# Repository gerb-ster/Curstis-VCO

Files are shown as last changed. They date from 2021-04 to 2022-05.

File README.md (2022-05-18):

# Curtis-VCO

This module is based on the classic CEM3340 VCO chip, although I’m using a AS3340 clone. I’ve took some inspiration from the Maximus VCO design from Thomas Henry. The CEM3340 outputs 3 waveforms with different output levels. To achieve a uniform 10 vpp output around 0 volt, I used a series of op-amps. In the first step the 3 levels is attenuated to 10 vpp, in the next step it’s being offset with 5v to make it swing around 0 volt. I’ve used a trimpot to fine-tune the offset.

The triangle output is then used to ‘wave shape’ a sine output. For this, I also used a classic design from Thomas.

I’ve already made some changes to the PCB design, there was an issue with the power rails on the IO board (hence the bodge wire), some transistor values where wrong, and I made some more room for a good timing cap.

### Update 18-05-2022

Small changes have been made to the io-board to fix an issue with PWM range knob. If you have an older board, you can remove R51 from the ioboard and replace it with a wire and replace R49 with a 91k resistor.

## Status: Finished

- done: first schematic & board design
- done: breadboard and test
- done: design frontpanel
- done: order PCB and build prototype

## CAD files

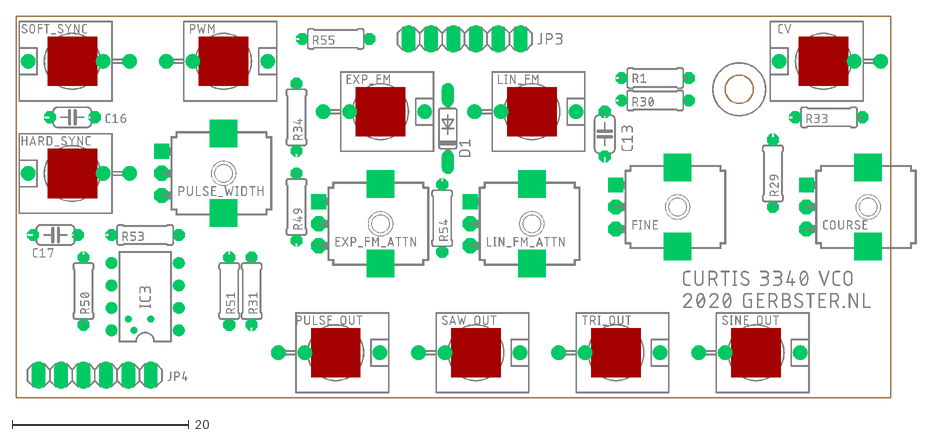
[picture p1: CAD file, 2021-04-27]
faceplates/curtis-vco-io.dxf
102.0 x 43.2

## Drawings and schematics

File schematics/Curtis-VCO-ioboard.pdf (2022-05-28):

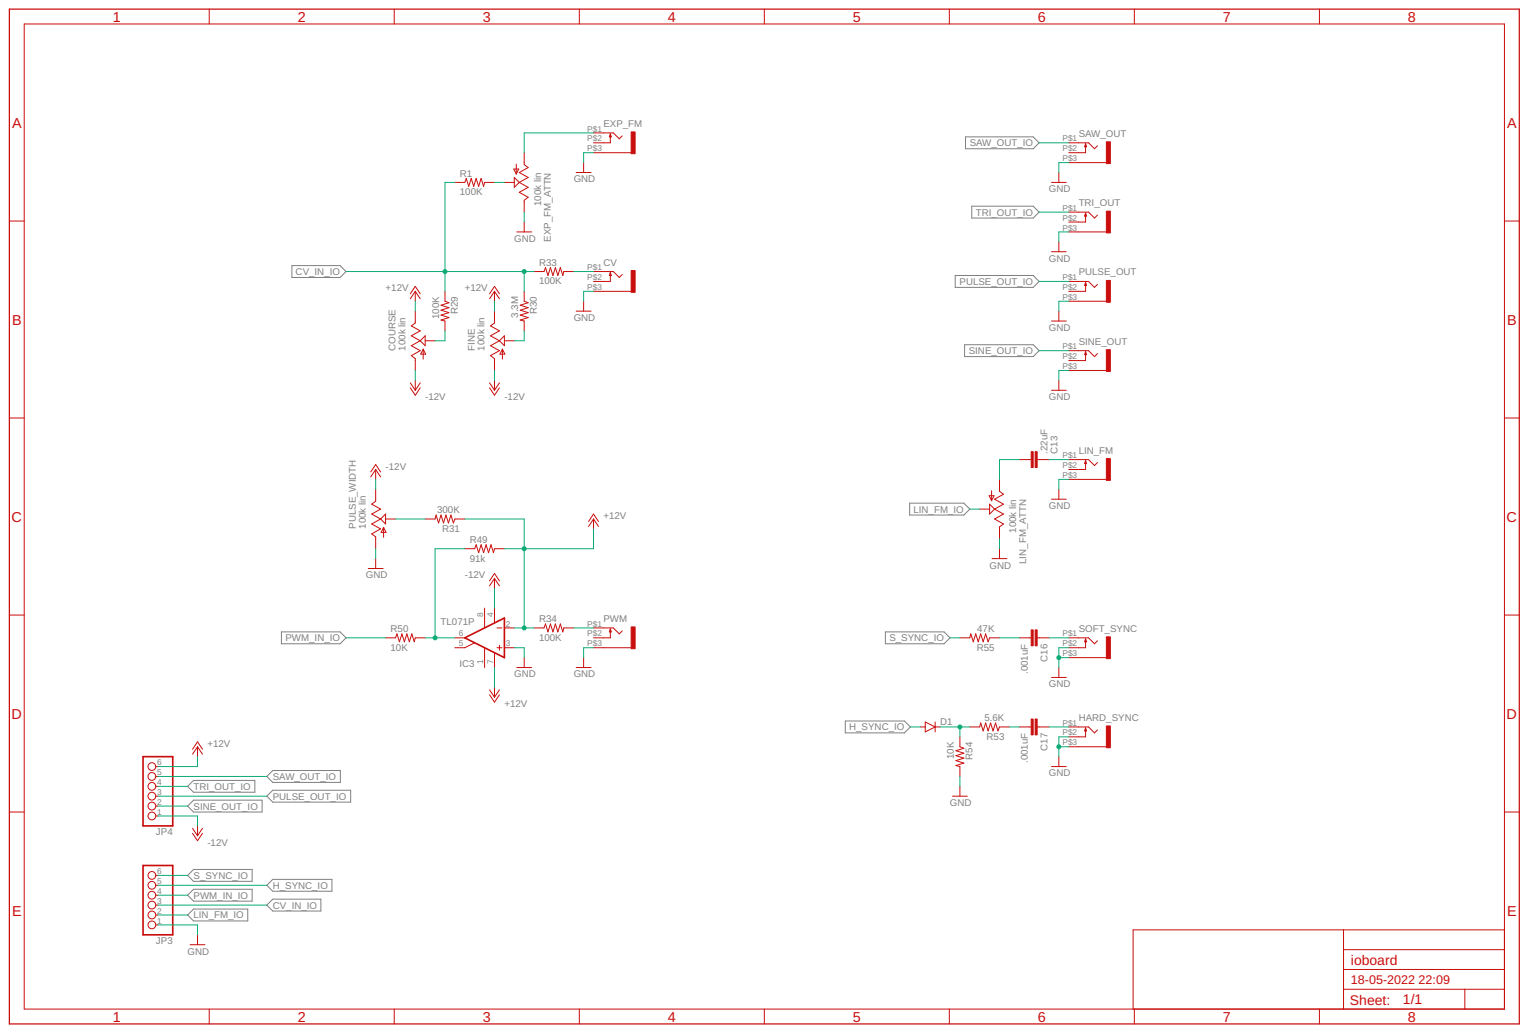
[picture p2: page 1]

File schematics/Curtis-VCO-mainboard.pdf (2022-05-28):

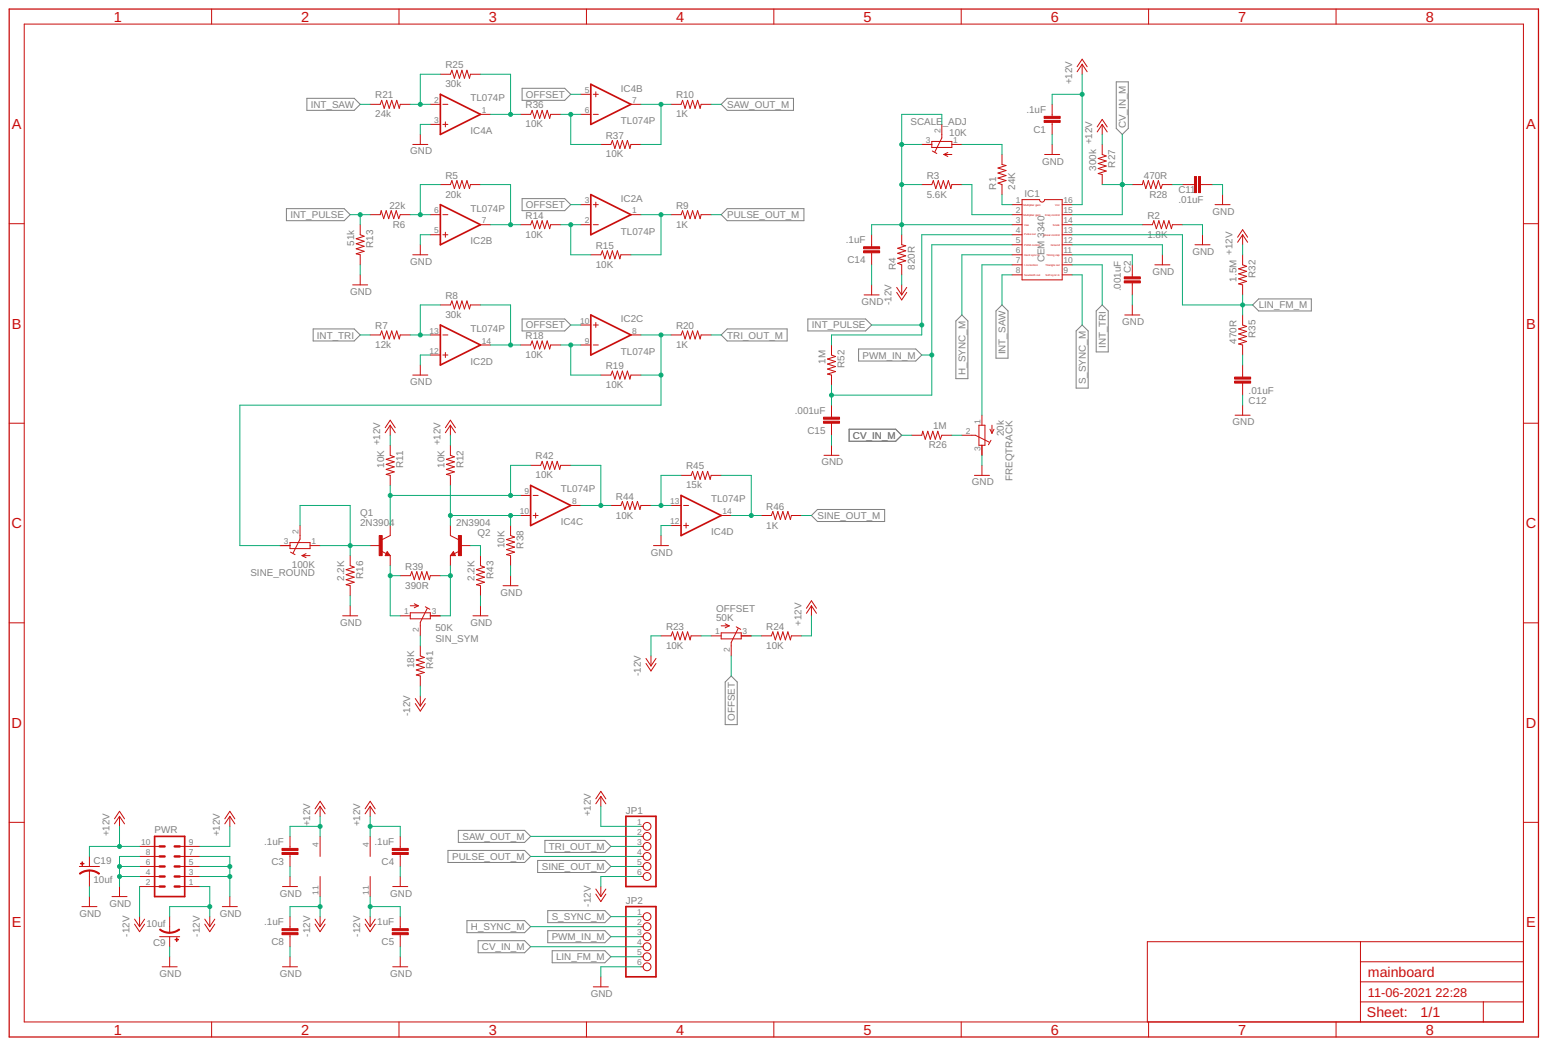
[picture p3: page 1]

Linear control Scale Freq control Vcc

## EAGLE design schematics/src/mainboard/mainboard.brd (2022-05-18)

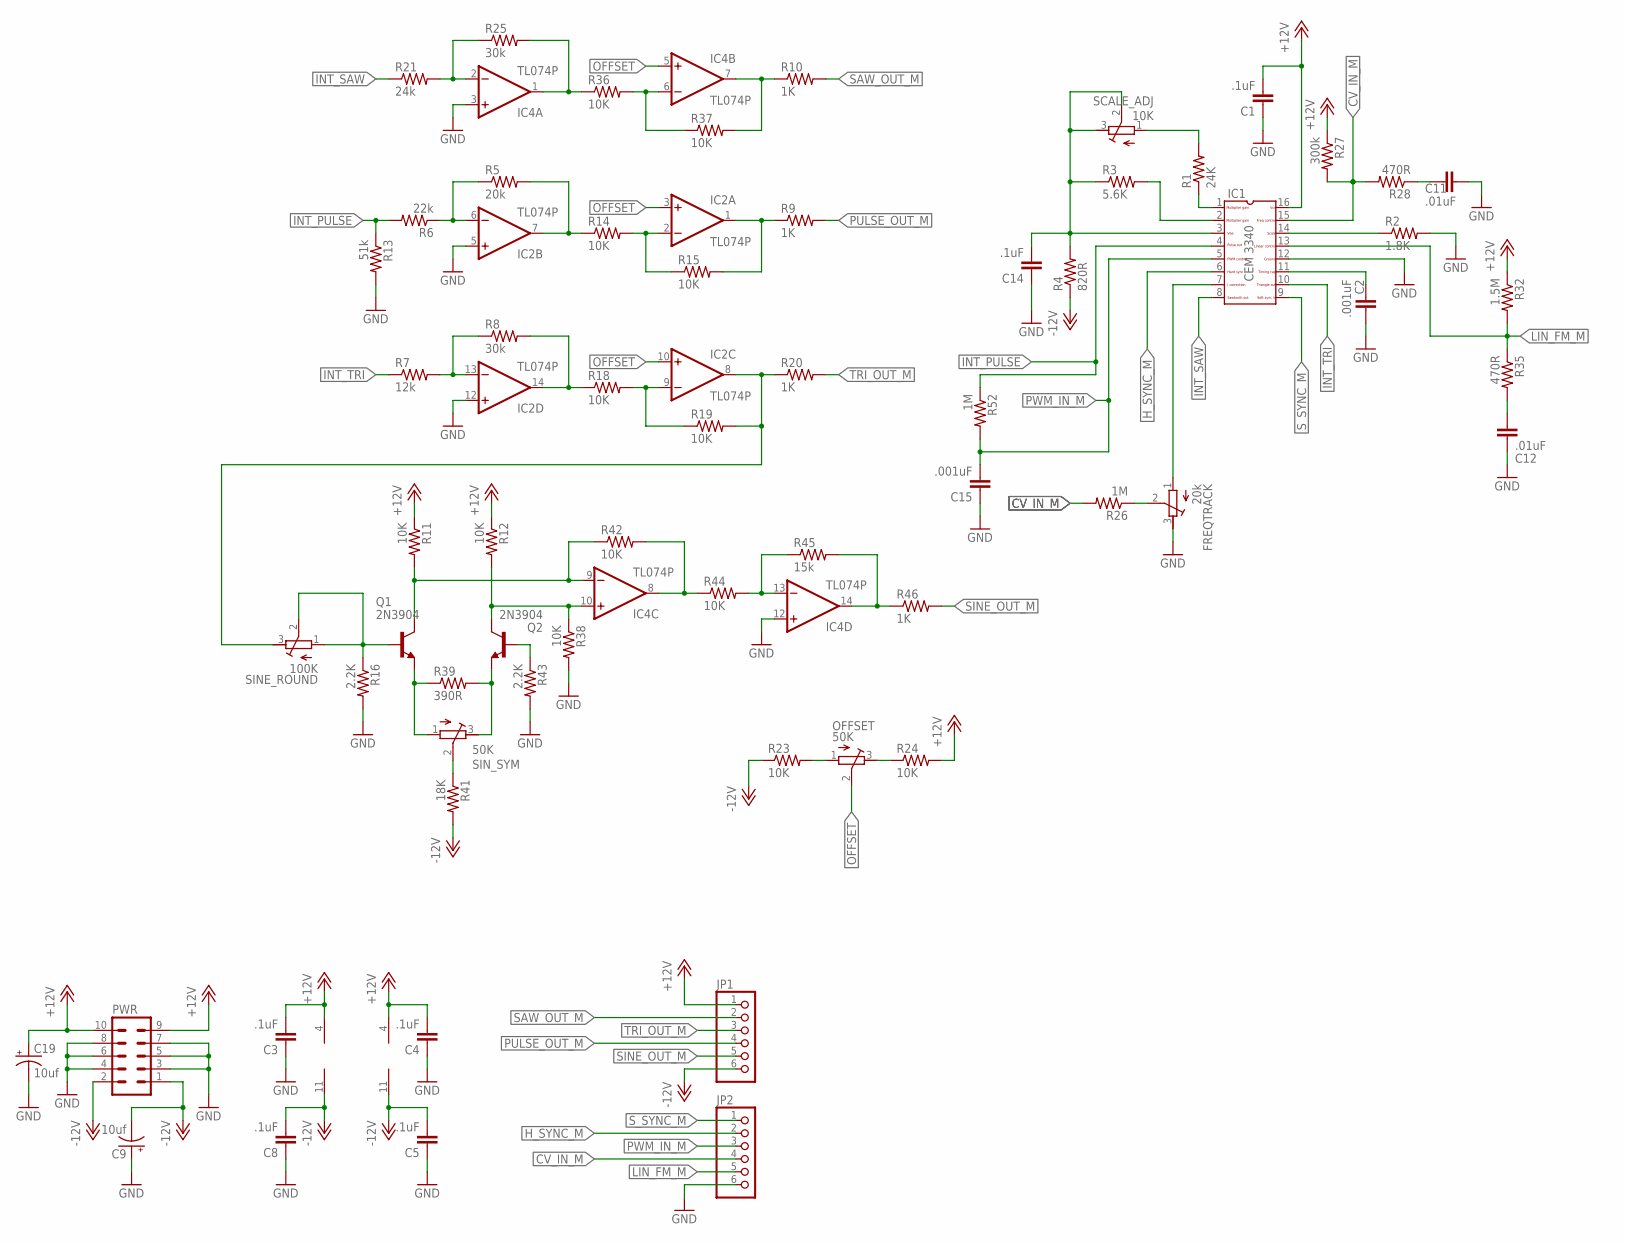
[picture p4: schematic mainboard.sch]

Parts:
C1, C3, C4, C5, C8, C14: .1uF; C050-024X044
C2: .001uF; C150-054X183
C9, C19: 10uf; E2,5-5
C11, C12: .01uF; C050-024X044
C15: .001uF; C050-024X044
FREQTRACK: 20k; RTRIM3296W
IC1: CEM3340; DIL16
IC2, IC4: TL074P; DIL14
JP1, JP2: PINHD-1X6; 1X06
OFFSET: 50K; RTRIM3296W
PWR: ML10
Q1, Q2: 2N3904; TO92
R1: 24K; 0207/7
R2: 1.8K; 0207/7
R3: 5.6K; 0207/7
R4: 820R; 0207/7
R5: 20k; 0207/7
R6: 22k; 0207/7
R7: 12k; 0207/7
R8, R25: 30k; 0207/7
R9, R10, R20, R46: 1K; 0207/7
R11, R12, R14, R15, R18, R19, R23, R24, R36, R37, R38, R42, R44: 10K; 0207/7
R13: 51k; 0207/7
R16, R43: 2.2K; 0207/7
R21: 24k; 0207/7
R26, R52: 1M; 0207/7
R27: 300k; 0207/7
R28, R35: 470R; 0207/7
R32: 1.5M; 0207/7
R39: 390R; 0207/7
R41: 18K; 0207/7
R45: 15k; 0207/7
SCALE_ADJ: 10K; RTRIM3296W
SINE_ROUND: 100K; RTRIM3296W
SIN_SYM: 50K; RTRIM3296W

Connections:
+12V: C1.2, C3.2, C4.2, C19.+, IC1.16, IC2.4 (V+), IC4.4 (V+), JP1.1, PWR.9, PWR.10, R11.1, R12.1, R24.2, R27.1, R32.1
-12V: C5.2, C8.2, C9.-, IC2.11 (V-), IC4.11 (V-), JP1.6, PWR.1, PWR.2, R4.1, R23.1, R41.2
CV_IN_M: IC1.15, JP2.4, R26.2, R27.2, R28.2
GND: C1.1, C2.2, C3.1, C4.1, C5.1, C8.1, C9.+, C11.1, C12.2, C14.1, C15.1, C19.-, FREQTRACK.3 (E), IC1.12, IC2.5 (+IN), IC2.12 (+IN), IC4.3 (+IN), IC4.12 (+IN), JP2.6, PWR.3, PWR.4, PWR.5, PWR.6, PWR.7, PWR.8, R2.2, R13.2, R16.2, R38.2, R43.2
HF_CORRECTION: FREQTRACK.1 (A), IC1.7
H_SYNC_M: IC1.6, JP2.2
INT_PULSE: IC1.4, R6.2, R13.1, R52.1
INT_SAW: IC1.8, R21.1
INT_TRI: IC1.10, R7.1
LIN_FM_M: IC1.13, JP2.5, R32.2, R35.1
unnamed: IC1.1, R1.1
unnamed: C2.1, IC1.11
unnamed: IC1.14, R2.1
unnamed: IC1.2, R3.2
unnamed: Q1.2 (B), R16.1, SINE_ROUND.1 (A), SINE_ROUND.2 (S)
unnamed: IC2.6 (-IN), R5.1, R6.1
unnamed: C14.2, IC1.3, R3.1, R4.2, SCALE_ADJ.2 (S), SCALE_ADJ.3 (E)
unnamed: R1.2, SCALE_ADJ.1 (A)
unnamed: IC4.1 (OUT), R25.2, R36.1
unnamed: IC4.9 (-IN), Q1.1 (C), R11.2, R42.1
unnamed: IC2.13 (-IN), R7.2, R8.1
unnamed: IC4.10 (+IN), Q2.1 (C), R12.2, R38.1
unnamed: IC2.14 (OUT), R8.2, R18.1
unnamed: IC2.7 (OUT), R5.2, R14.1
unnamed: IC2.2 (-IN), R14.2, R15.1
unnamed: R41.1, SIN_SYM.2 (S)
unnamed: Q1.3 (E), R39.1, SIN_SYM.1 (A)
unnamed: IC2.9 (-IN), R18.2, R19.1
unnamed: OFFSET.1 (A), R23.2
unnamed: OFFSET.3 (E), R24.1
unnamed: FREQTRACK.2 (S), R26.1
unnamed: C11.2, R28.1
unnamed: IC2.1 (OUT), R9.1, R15.2
unnamed: IC4.6 (-IN), R36.2, R37.1
unnamed: C12.1, R35.2
unnamed: IC2.8 (OUT), R19.2, R20.1, SINE_ROUND.3 (E)
unnamed: Q2.3 (E), R39.2, SIN_SYM.3 (E)
unnamed: IC4.2 (-IN), R21.2, R25.1
unnamed: IC4.8 (OUT), R42.2, R44.1
unnamed: IC4.7 (OUT), R10.1, R37.2
unnamed: Q2.2 (B), R43.1
unnamed: IC4.14 (OUT), R45.2, R46.1
unnamed: IC4.13 (-IN), R44.2, R45.1
OFFSET: IC2.3 (+IN), IC2.10 (+IN), IC4.5 (+IN), OFFSET.2 (S)
PULSE_OUT_M: JP1.4, R9.2
PWM_IN_M: C15.2, IC1.5, JP2.3, R52.2
SAW_OUT_M: JP1.2, R10.2
SINE_OUT_M: JP1.5, R46.2
S_SYNC_M: IC1.9, JP2.1
TRI_OUT_M: JP1.3, R20.2

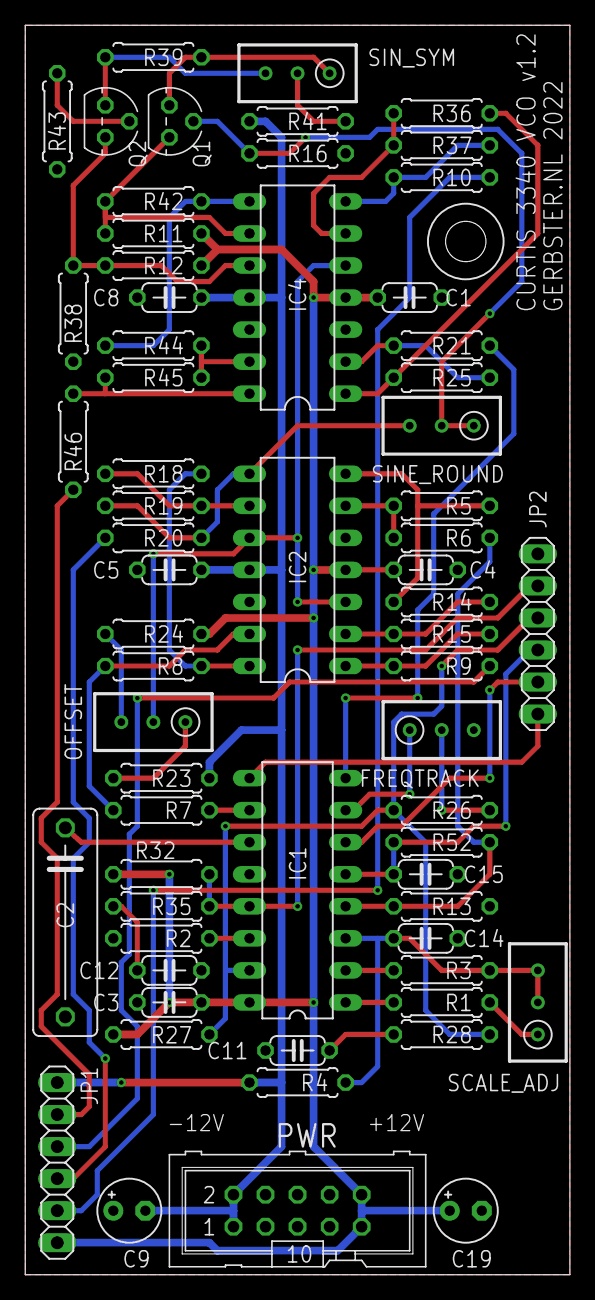
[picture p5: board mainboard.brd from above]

Board: 2 copper layers, 43.2 x 99.1 mm, 64 parts (0 on the bottom side), 50 nets.

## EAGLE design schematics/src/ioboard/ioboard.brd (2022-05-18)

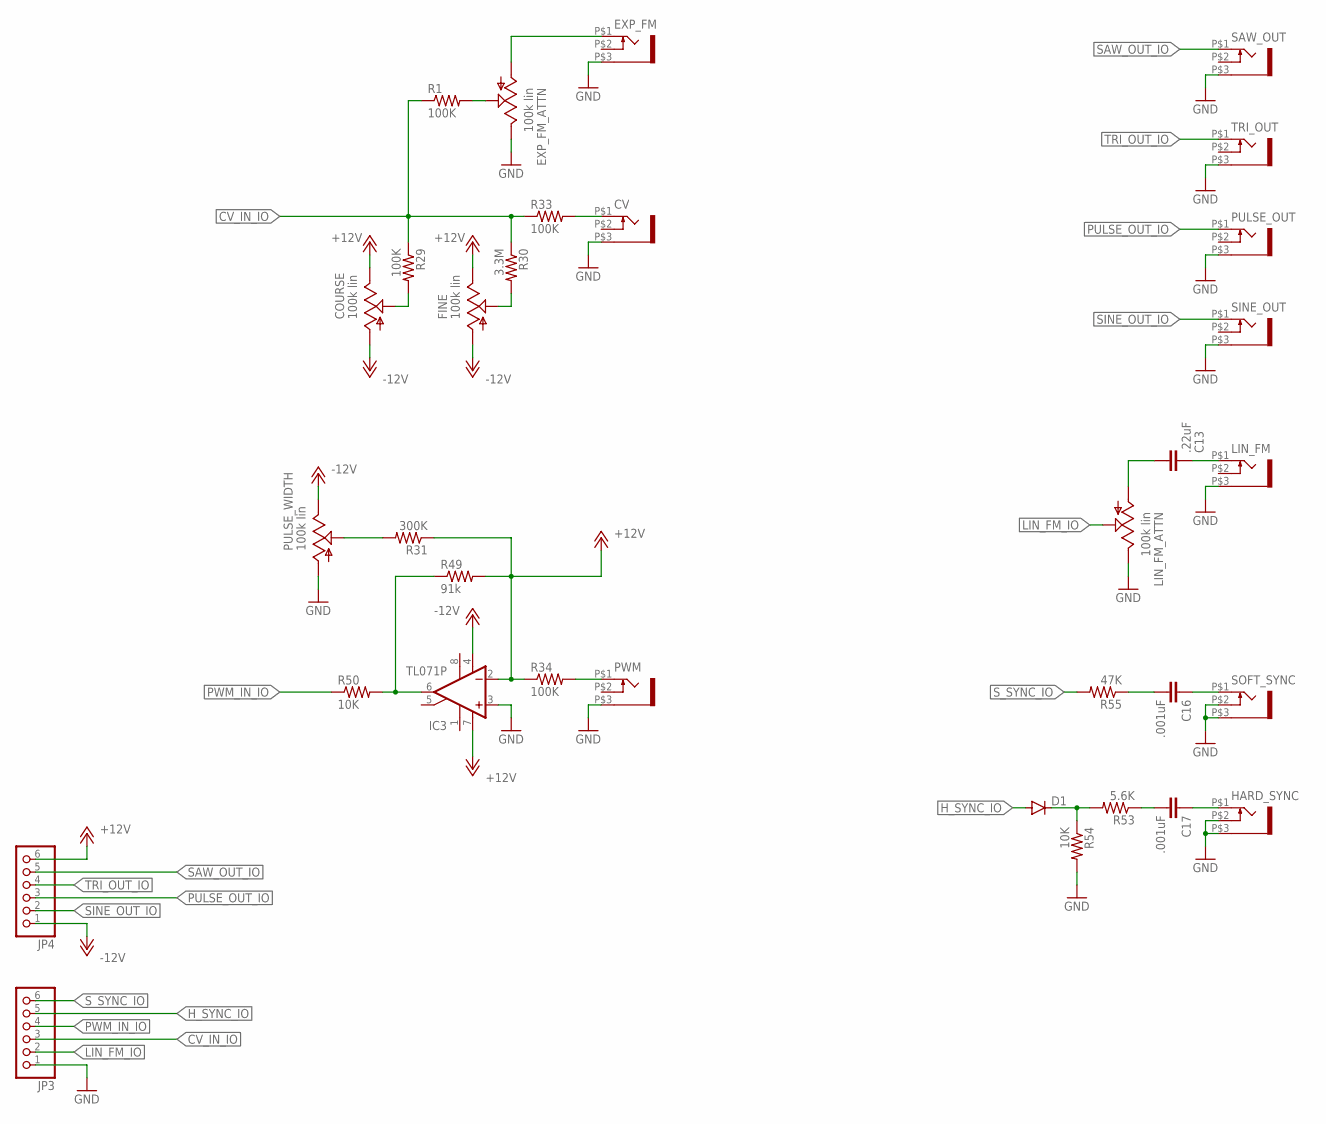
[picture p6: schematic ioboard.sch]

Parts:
C13: .22uF; C050-024X044
C16, C17: .001uF; C050-024X044
COURSE: 100k lin; EVUF
CV: WQP-PJ301M-12_JACK
D1: 1N4148DO35-7; DO35-7
EXP_FM: WQP-PJ301M-12_JACK
EXP_FM_ATTN: 100k lin; EVUF
FINE: 100k lin; EVUF
HARD_SYNC: WQP-PJ301M-12_JACK
IC3: TL071P; DIL08
JP3, JP4: PINHD-1X6; 1X06
LIN_FM: WQP-PJ301M-12_JACK
LIN_FM_ATTN: 100k lin; EVUF
PULSE_OUT: WQP-PJ301M-12_JACK
PULSE_WIDTH: 100k lin; EVUF
PWM: WQP-PJ301M-12_JACK
R1, R29, R33, R34: 100K; 0207/7
R30: 3.3M; 0207/7
R31: 300K; 0207/7
R49: 91k; 0207/7
R50, R54: 10K; 0207/7
R53: 5.6K; 0207/7
R55: 47K; 0207/7
SAW_OUT: WQP-PJ301M-12_JACK
SINE_OUT: WQP-PJ301M-12_JACK
SOFT_SYNC: WQP-PJ301M-12_JACK
TRI_OUT: WQP-PJ301M-12_JACK

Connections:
+12V: COURSE.3 (E), FINE.3 (E), IC3.2 (-IN), IC3.7 (V+), JP4.6, R31.1, R34.1, R49.2
-12V: COURSE.1 (A), FINE.1 (A), IC3.4 (V-), JP4.1, PULSE_WIDTH.3 (E)
CV_IN_IO: JP3.3, R1.1, R29.1, R30.1, R33.1
GND: CV.P$3 (1), EXP_FM.P$3 (1), EXP_FM_ATTN.3 (E), HARD_SYNC.P$2 (3), HARD_SYNC.P$3 (1), IC3.3 (+IN), JP3.1, LIN_FM.P$3 (1), LIN_FM_ATTN.3 (E), PULSE_OUT.P$3 (1), PULSE_WIDTH.1 (A), PWM.P$3 (1), R54.2, SAW_OUT.P$3 (1), SINE_OUT.P$3 (1), SOFT_SYNC.P$2 (3), SOFT_SYNC.P$3 (1), TRI_OUT.P$3 (1)
H_SYNC_IO: D1.A, JP3.5
LIN_FM_IO: EXP_FM_ATTN.2 (S), JP3.2, LIN_FM_ATTN.2 (S), R1.2
unnamed: EXP_FM.P$1 (2), EXP_FM_ATTN.1 (A)
unnamed: COURSE.2 (S), R29.2
unnamed: FINE.2 (S), R30.2
unnamed: CV.P$1 (2), R33.2
unnamed: PWM.P$1 (2), R34.2
unnamed: PULSE_WIDTH.2 (S), R31.2
unnamed: C13.2, LIN_FM.P$1 (2)
unnamed: C13.1, LIN_FM_ATTN.1 (A)
unnamed: C16.1, SOFT_SYNC.P$1 (2)
unnamed: IC3.6 (OUT), R49.1, R50.2
unnamed: C16.2, R55.1
unnamed: C17.1, HARD_SYNC.P$1 (2)
unnamed: C17.2, R53.1
unnamed: D1.C, R53.2, R54.1
PULSE_OUT_IO: JP4.3, PULSE_OUT.P$1 (2)
PWM_IN_IO: JP3.4, R50.1
SAW_OUT_IO: JP4.5, SAW_OUT.P$1 (2)
SINE_OUT_IO: JP4.2, SINE_OUT.P$1 (2)
S_SYNC_IO: JP3.6, R55.2
TRI_OUT_IO: JP4.4, TRI_OUT.P$1 (2)

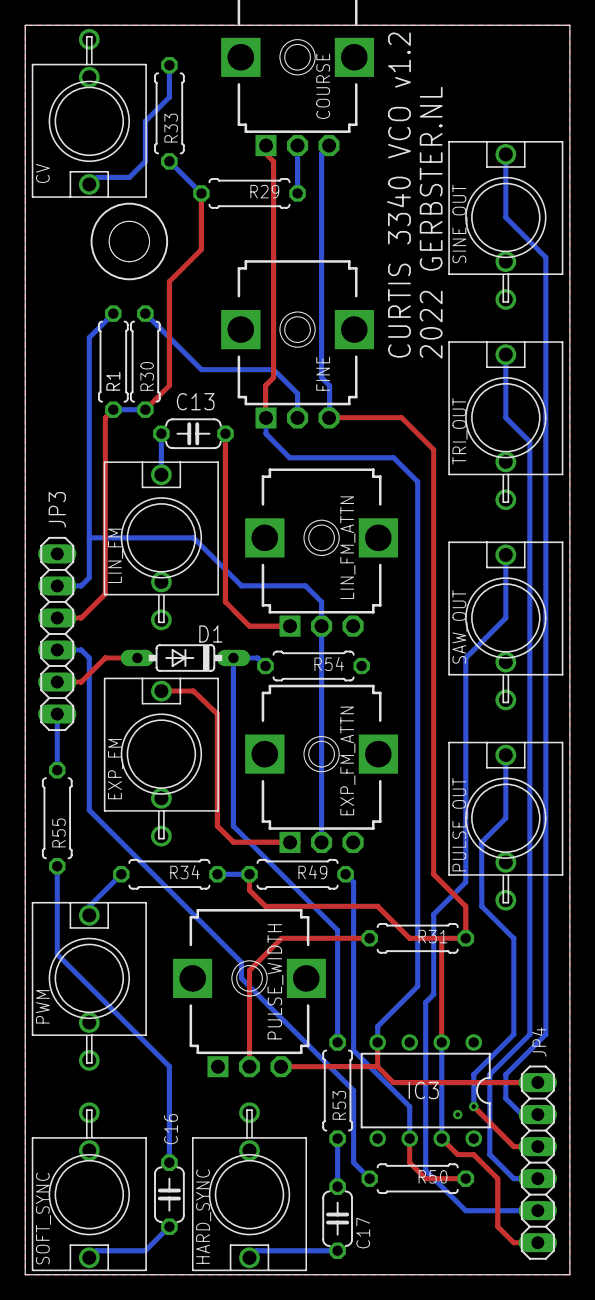
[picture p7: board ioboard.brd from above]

Board: 2 copper layers, 43.2 x 99.1 mm, 33 parts (0 on the bottom side), 26 nets.

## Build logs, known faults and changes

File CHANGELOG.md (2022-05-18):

# Changelog

All notable changes to this project will be documented in this file.

The format is based on [Keep a Changelog](https://keepachangelog.com/en/1.0.0/),
and this project adheres to [Semantic Versioning](https://semver.org/spec/v2.0.0.html).

## [1.2.0] - 2022-18-05

### Changed

- removed R51
- changed R49 to 91k

## [1.1.0] - 2021-07-05

### Changed

- Fixed a faulty powerline on the IO Board
- Made some room on the Mainboard to accomodate a good timing cap
- Fixed some values for a couple of resistors

## [1.0.0] - 2021-01-05

### Added

- Inintial repo setup

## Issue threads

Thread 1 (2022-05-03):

Range of PWM knob

jpa73, 2022-05-03:
This control causes the VCO to cut out when either fully clockwise or fully anticlockwise.  The scope shows the pulse width changing as you'd expect over the rest of the range.  This may be by design, but in use it may benefit from reducing the range of the Pulse Width control to avoid the VCO from cutting out at either end of the range.

jpa73, 2022-05-03:
Remove R51 and change out R49 to 91k.  This moderates the upper and lower ranges so that as the minimum or maximum settings the PW does not cause the VCO to cut out.

jpa73, 2022-05-13:
This could be a documented option or a permanent change to the BOM.

gerb-ster, 2022-05-18:
@jpa73 you are right, I've updated the schematics & documentation! version 1.2 is released :-) thanks for the debugging and suggestions!

Closed 2022-05-18.

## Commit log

2021-04-18 Add PDF files and restructured
    [Curtis3340-VCO.brd, Curtis3340-VCO.sch]
2021-04-27 Added faceplate designs
    [curtis-vco-io.dxf]
2021-05-07 Added files and structure
    [Curtis-VCO-ioboard.GBL, Curtis-VCO-ioboard.GBO, Curtis-VCO-ioboard.GBP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]
2021-05-07 small typos
    [Curtis-VCO-ioboard.XLN, Curtis-VCO-mainboard.XLN, gerber_job.gbrjob]
2021-06-15 Updated Schematics, Fixed Power Socket orientation
    [Curtis-VCO-ioboard.XLN, Curtis-VCO-mainboard.GBL, Curtis-VCO-mainboard.GBS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]
2021-08-06 Updated some schematics and docs
    [Curtis-VCO-ioboard.GBL, Curtis-VCO-ioboard.GBO, Curtis-VCO-ioboard.GBP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]
2022-05-04 Fixed schematics & descriptions
    [Curtis-VCO-ioboard.GBL, Curtis-VCO-ioboard.GBO, Curtis-VCO-ioboard.GBP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]
2022-05-17 Updated Firmware
    [Curtis-VCO-ioboard.XLN, Curtis-VCO-mainboard.XLN, gerber_job.gbrjob]
2022-05-18 Updated Faceplates
    [Curtis-VCO-ioboard.XLN, Curtis-VCO-mainboard.XLN, gerber_job.gbrjob]
2022-05-18 Fixed issues
    [Curtis-VCO-ioboard.GBL, Curtis-VCO-ioboard.GBS, Curtis-VCO-ioboard.GTL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]
2022-05-21 Fixed schematics
    [Curtis-VCO-ioboard.XLN, Curtis-VCO-mainboard.XLN, gerber_job.gbrjob]
2022-05-28 General updates
    [Curtis-VCO-ioboard.GKO, Curtis-VCO-mainboard.GKO, copper_bottom.gbr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]
